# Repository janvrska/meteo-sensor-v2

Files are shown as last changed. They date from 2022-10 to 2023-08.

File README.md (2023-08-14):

# Meteo sensor v2
## Custom PCB project of LoraWAN weather sensor

<div>


</div>

**Components :**
 - [Atmel ATMega3208](https://cz.mouser.com/ProductDetail/Microchip-Technology-Atmel/ATMEGA3208-AFR?qs=y6ZabgHbY%252ByqMua8ssBYRQ==) 
 - [Lora E5 SoC](https://cz.mouser.com/ProductDetail/Seeed-Studio/317990687?qs=hd1VzrDQEGhZOj13wvzSLA==)
 - [Sensirion SHT41](https://cz.mouser.com/ProductDetail/Sensirion/SHT41-AD1B-R2?qs=XAiT9M5g4x92rdly9nbdGg==)
 - [IPX connector](https://cz.mouser.com/ProductDetail/Amphenol-RF/A-1JB?qs=ncxkyCpAYDBidtvTkuzl1Q==)
 - 100 nF capacitors
 - 10 uF capacitors
 - 10k Ω resistors
 - 22 Ω resistors
 - pin headers for debugging, flashing

**Software:**
 - [MegaCoreX](https://github.com/MCUdude/MegaCoreX) - environment for Arduino compatibility  (Serial, Wire, Interrupts)
 - [Sensirion I2C SHT4X library](https://github.com/Sensirion/arduino-i2c-sht4x) -  SHT41 sensor data reading
 - [Platformio](https://platformio.org/)  - development, flashing ATMega

This project assumes, that credentials were configured by Serial [Lora E5 AT Commands](https://files.seeedstudio.com/products/317990687/res/LoRa-E5%20AT%20Command%20Specification_V1.0%20.pdf) (DevEUI, AppKey) before flashing the project code. 

**Flow:**
 1. Should be in a range of some nearest LoraWAN Gateway (can look on [TTNMapper](https://ttnmapper.org/))
 2. Power on the device with 3.3 V (2x AA or 2x AAA batteries) connected to VCC and GND pins (look at [board schema](https://github.com/janvrska/meteo-sensor-v2/blob/main/main-board/board.pdf), SV1 blue line GND down, red line VCC)
 3. The device will try to OTA join configured LoraWAN network
 4. Broadcast data packet (temperature, humidity, voltage)
 5. 2.5 minutes sleeping (configured for DR5, spread factor 7, make sure to not violate ETSI regulations or TTN fair access policy. Should be [calculated](https://avbentem.github.io/airtime-calculator/ttn/eu868) before use)
 6. Back to step 4.
 ```mermaid
stateDiagram
    [*] --> PowerOn
    PowerOn --> Join
    Join --> Measure
    Measure --> SendPacket
    SendPacket --> Sleep
    Sleep --> Measure
```
 
 **Low power** (250 µA measured in sleep)
 - use AT+DR=DR5 (will work only if a gateway is close or open area without a lot of RF noise)
 - use AT+POWER=2 (same above)
 - other AT commands already used in code

**TTN**

Use this payload [formatter](https://github.com/janvrska/meteo-sensor-v2/blob/main/ttn-payload-formatter.js) for decoding. Weather data can be later processed with some TTN integration options (MQTT, webhooks...) 
ttn

From personal testing, the sensor could transmit for 4 months on 2x AA batteries with default settings (DR5, AT+POWER=2)

**Photos of setup:**

Soldered by hand and hot air gun
<div>



</div>

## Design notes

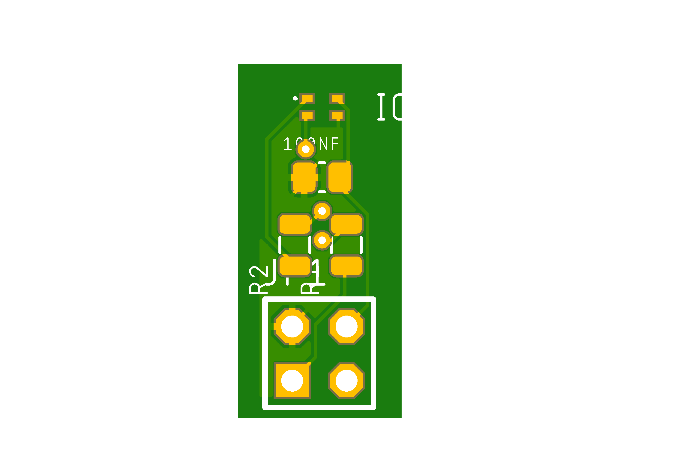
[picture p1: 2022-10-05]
sensirion-board/sensor.png

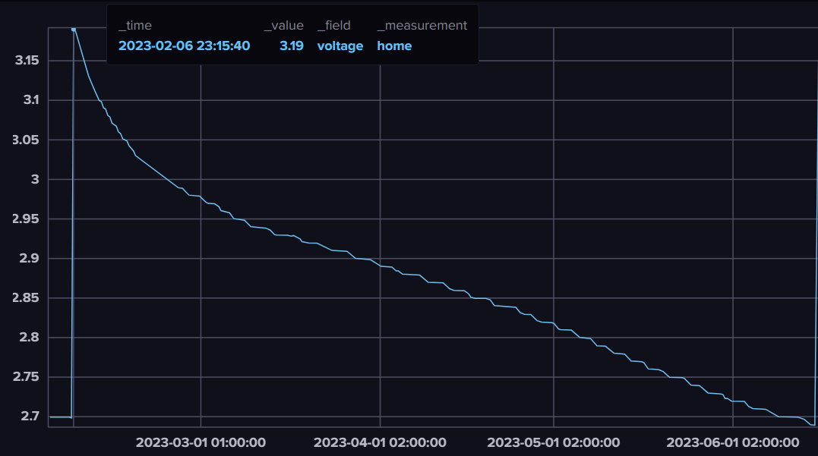
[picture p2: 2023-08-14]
consumption-graphs/4-months battery profile.png

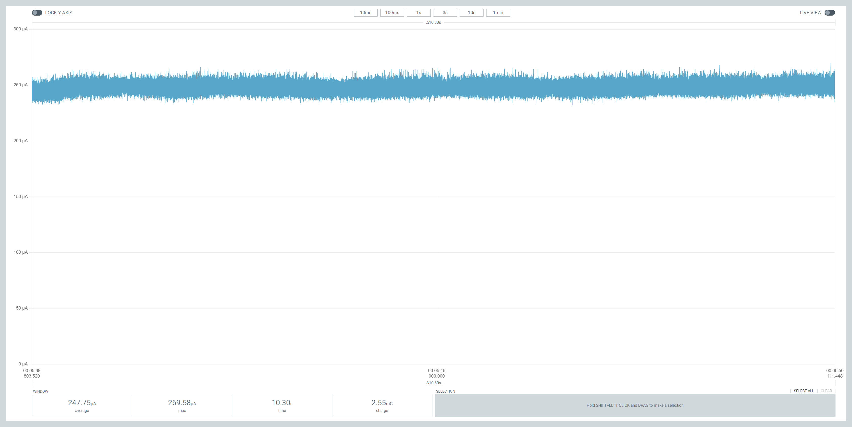
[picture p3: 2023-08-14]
consumption-graphs/sleep.png

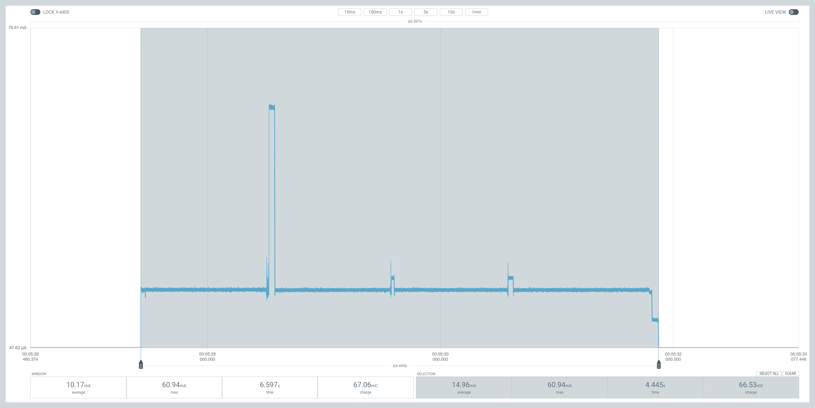
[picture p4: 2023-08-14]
consumption-graphs/uplink.png

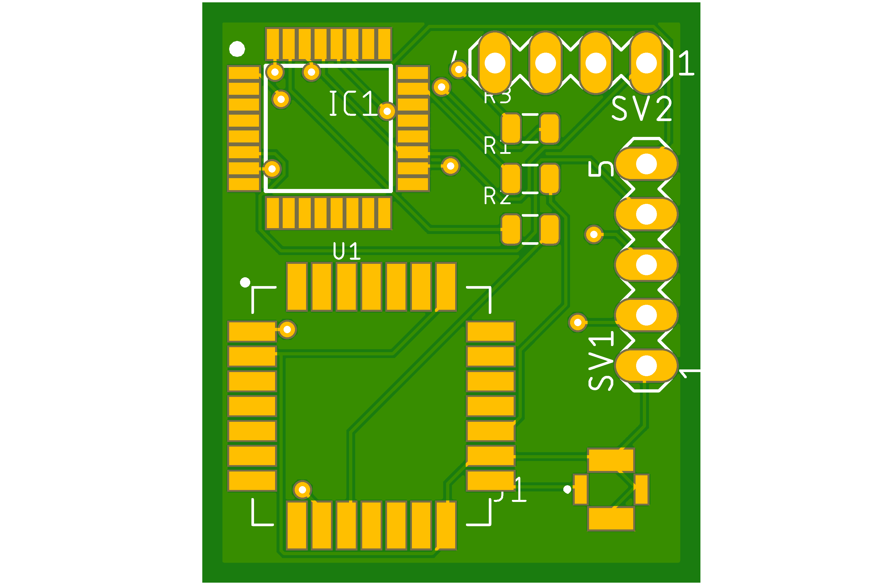
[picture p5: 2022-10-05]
main-board/board.png

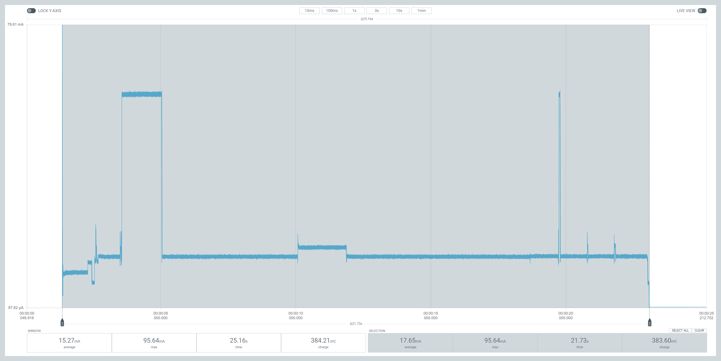
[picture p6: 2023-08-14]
consumption-graphs/join.png

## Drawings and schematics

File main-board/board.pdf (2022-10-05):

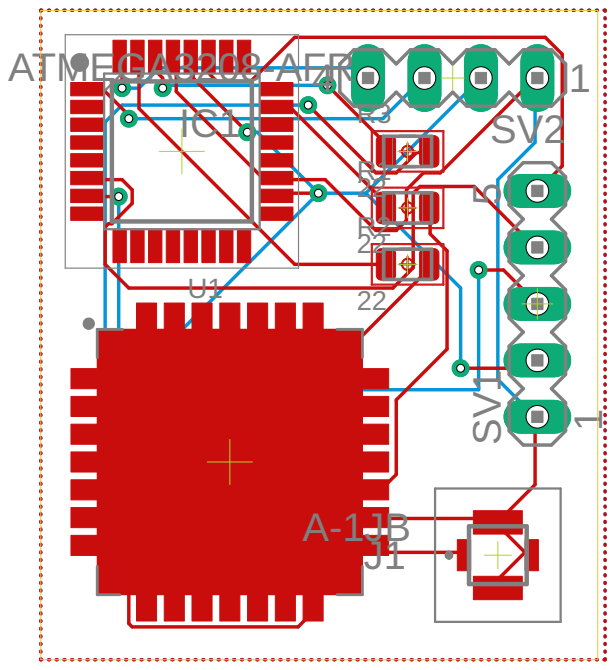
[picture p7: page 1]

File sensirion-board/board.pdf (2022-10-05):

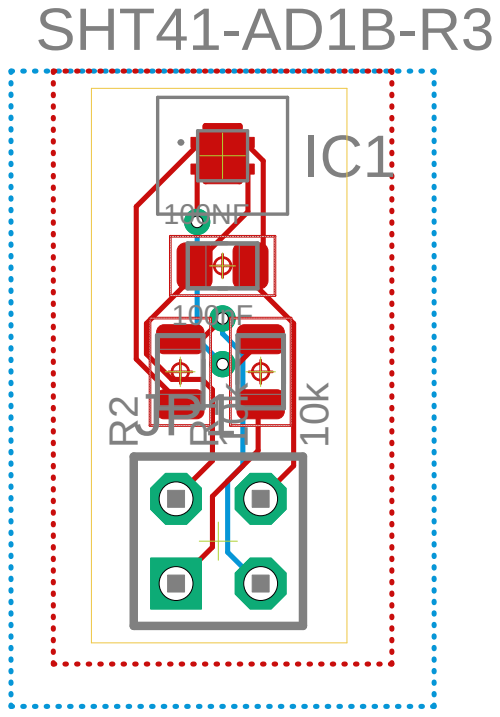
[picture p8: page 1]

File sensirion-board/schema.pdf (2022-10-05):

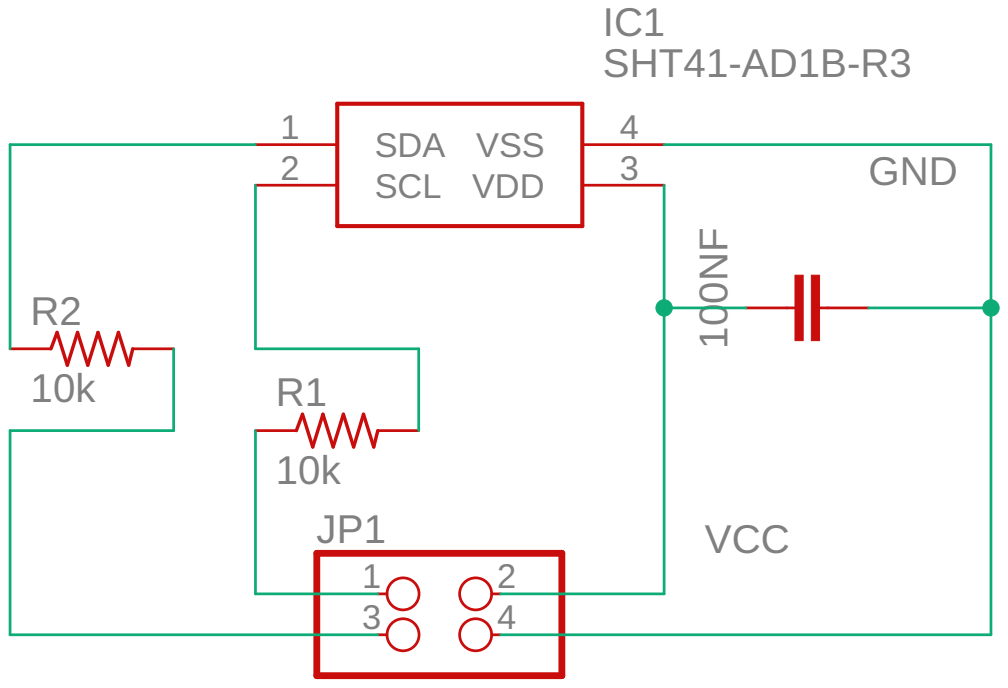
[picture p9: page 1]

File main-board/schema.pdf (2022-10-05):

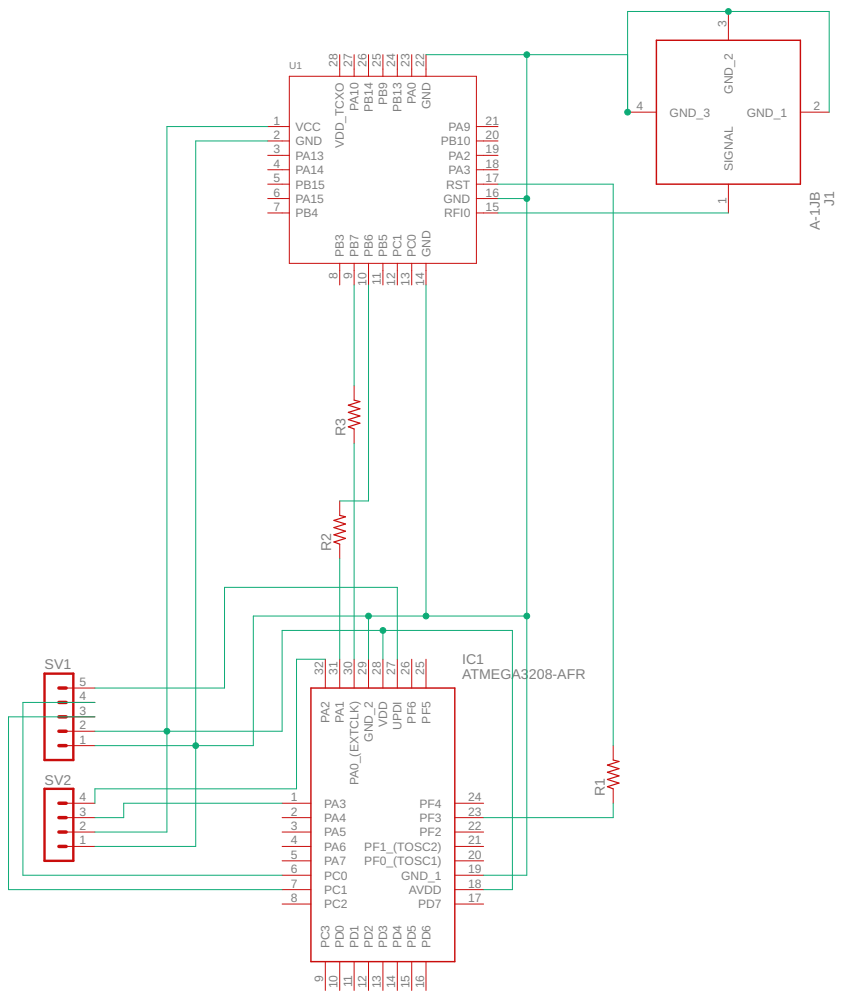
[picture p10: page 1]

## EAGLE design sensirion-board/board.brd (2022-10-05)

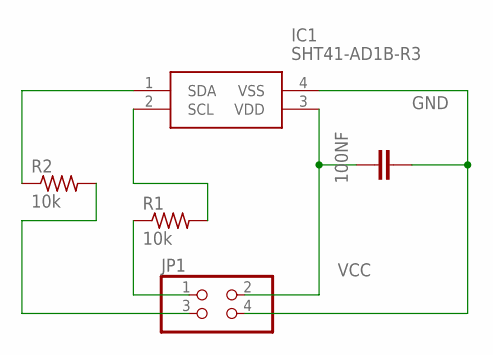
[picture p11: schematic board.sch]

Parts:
100NF: 100nF; CAP_0805
IC1: SHT41-AD1B-R3; SHT41AD1BR3
JP1: PINHD-2X2; 2X02
R1, R2: 10k; RES_0805

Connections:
GND: 100NF.2, IC1.4 (VSS), JP1.4
unnamed: JP1.3, R2.2
unnamed: IC1.2 (SCL), R1.2
unnamed: JP1.1, R1.1
unnamed: IC1.1 (SDA), R2.1
VCC: 100NF.1, IC1.3 (VDD), JP1.2

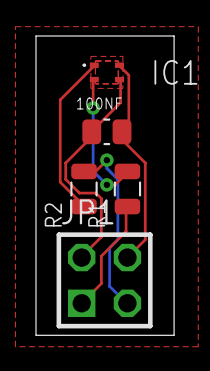
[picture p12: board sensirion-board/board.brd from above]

Board: 2 copper layers, 7.7 x 16.6 mm, 5 parts (0 on the bottom side), 6 nets.

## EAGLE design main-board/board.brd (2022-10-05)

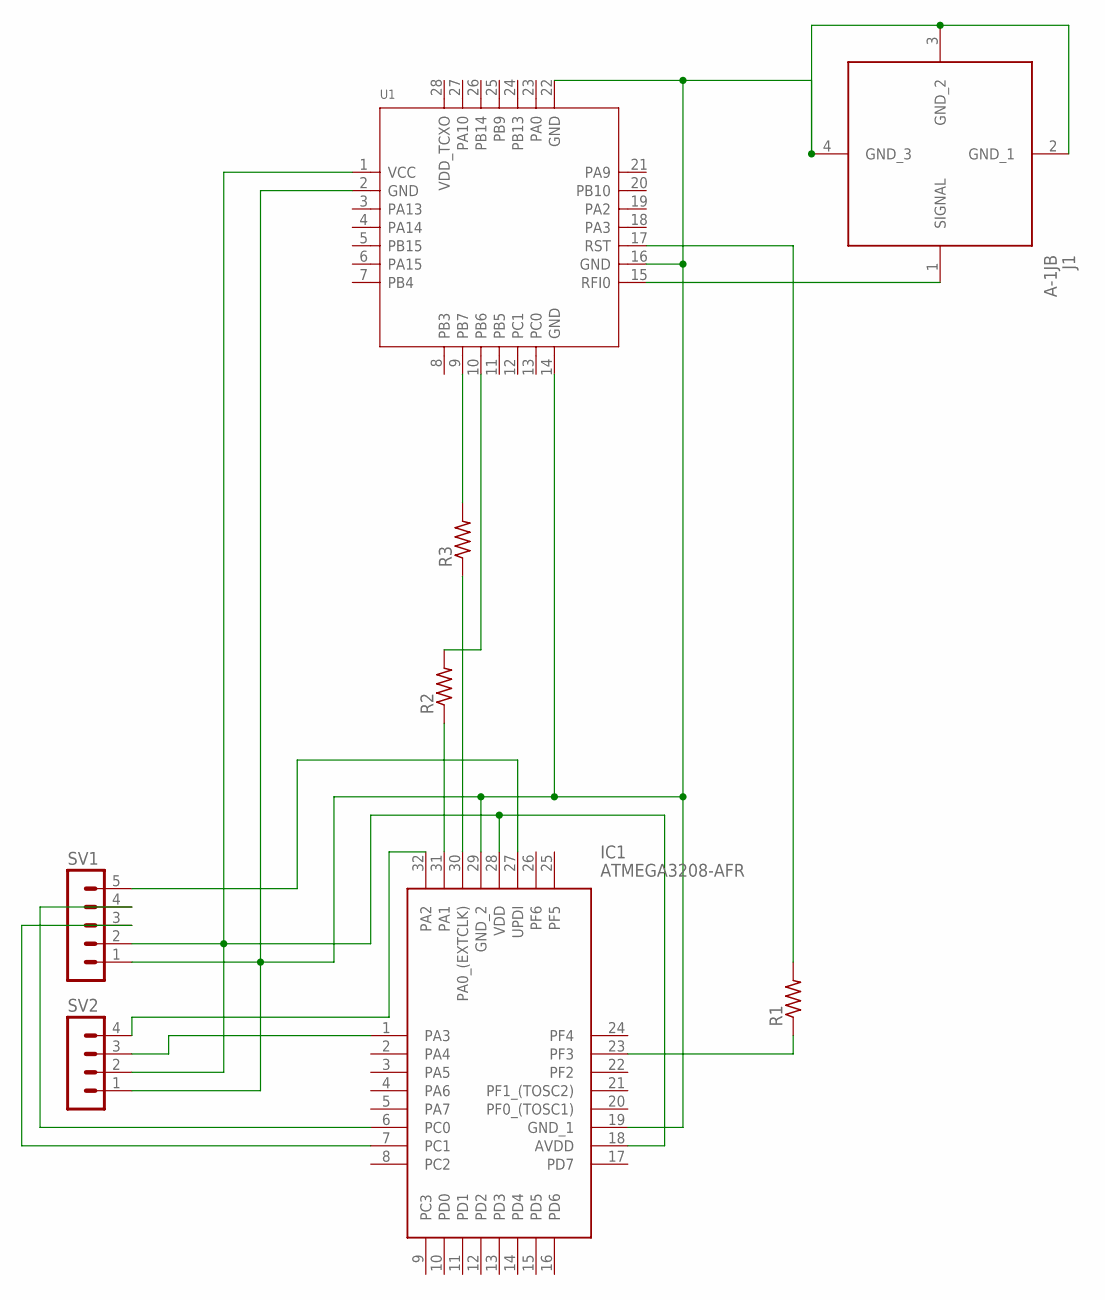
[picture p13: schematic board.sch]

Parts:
IC1: ATMEGA3208-AFR; QFP80P900X900X120-32N
J1: A-1JB; A1JB
R1, R2, R3: 22; RES_0805
SV1: MA05-1
SV2: MA04-1
U1: MODULE_LORA_E5; MODULE28P-1.25-12X12X2.5MM

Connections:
unnamed: IC1.19 (GND_1), IC1.29 (GND_2), J1.2 (GND_1), J1.3 (GND_2), J1.4 (GND_3), SV1.1, SV2.1, U1.2 (GND), U1.14 (GND), U1.16 (GND), U1.22 (GND)
unnamed: IC1.27 (UPDI), SV1.5
unnamed: IC1.18 (AVDD), IC1.28 (VDD), SV1.2, SV2.2, U1.1 (VCC)
unnamed: R1.2, U1.17 (RST)
unnamed: J1.1 (SIGNAL), U1.15 (RFI0)
unnamed: R3.2, U1.9 (PB7)
unnamed: R2.2, U1.10 (PB6)
unnamed: IC1.23 (PF3), R1.1
unnamed: IC1.31 (PA1), R2.1
unnamed: IC1.30 (PA0_(EXTCLK)), R3.1
unnamed: IC1.32 (PA2), SV2.4
unnamed: IC1.1 (PA3), SV2.3
unnamed: IC1.6 (PC0), SV1.4
unnamed: IC1.7 (PC1), SV1.3

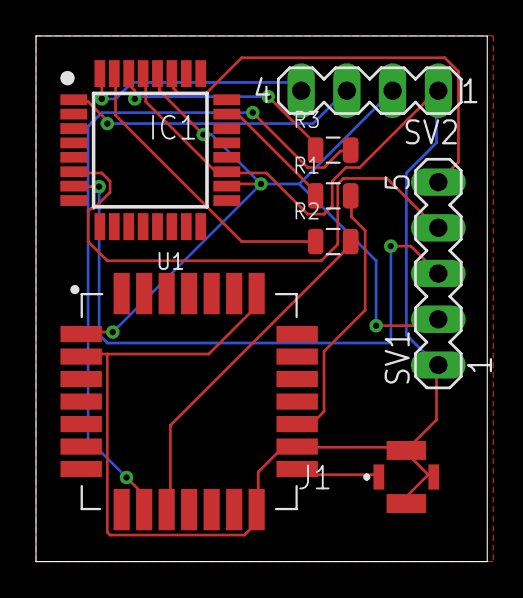
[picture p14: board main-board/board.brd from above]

Board: 2 copper layers, 25.1 x 29.2 mm, 8 parts (0 on the bottom side), 14 nets.

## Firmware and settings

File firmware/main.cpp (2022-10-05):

#include <Arduino.h>
#include <SensirionI2CSht4x.h>
#include <Wire.h>

#include <avr/interrupt.h>
#include <avr/sleep.h>
#include <avr/wdt.h>

SensirionI2CSht4x sht4x;

void wakeUp() {
    detachInterrupt(1);
}

const int getVoltage() {
    Serial.flush();
    Serial.end();
    
    delay(10);

    Serial.begin(9600);
    Serial.flush();

    delay(10);

    Serial.println("AT+VDD");

    delay(10);

    String vcc = Serial.readStringUntil('\0');
    vcc.replace("+VDD: ","");
    vcc.replace("V","");
    vcc.trim();

    return vcc.toFloat() / 0.01;
}

void setup() {
    set_sleep_mode(SLEEP_MODE_PWR_DOWN);
    sleep_enable();

    Serial.begin(9600);
    delay(100);

    while (!Serial1) {
        delay(100);
    }

    Wire.begin();
    sht4x.begin(Wire);

    Serial.println("AT+LOG=QUIET");
    delay(2000);

    Serial.println("AT+JOIN");
    delay(15000);

    Serial.println("AT+POWER=2");
    delay(100);

    Serial.println("AT+LW=DUMRX,OFF");
    delay(100);
}


void loop() {
    float temp;
    float hum;

    sht4x.measureHighPrecision(temp, hum);

    const int tempInt {temp / 0.01};
    const int humInt {hum / 0.01};
 
    const int voltage {getVoltage()};
    Serial.printf("AT+MSGHEX=%04X%04X%04X\n",tempInt,humInt,voltage);
    delay(3300);

    Serial.println("AT+LOWPOWER=150000");
    delay(50);

    attachInterrupt(1,wakeUp,CHANGE);
    delay(50);

    sleep_enable();
    sleep_cpu();
}

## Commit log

2022-10-05 project cleanup
    [board.brd, board.sch]
2022-10-05 add boards schema
    [board.brd, board.sch]
2023-08-14 add power profiles, correct values
